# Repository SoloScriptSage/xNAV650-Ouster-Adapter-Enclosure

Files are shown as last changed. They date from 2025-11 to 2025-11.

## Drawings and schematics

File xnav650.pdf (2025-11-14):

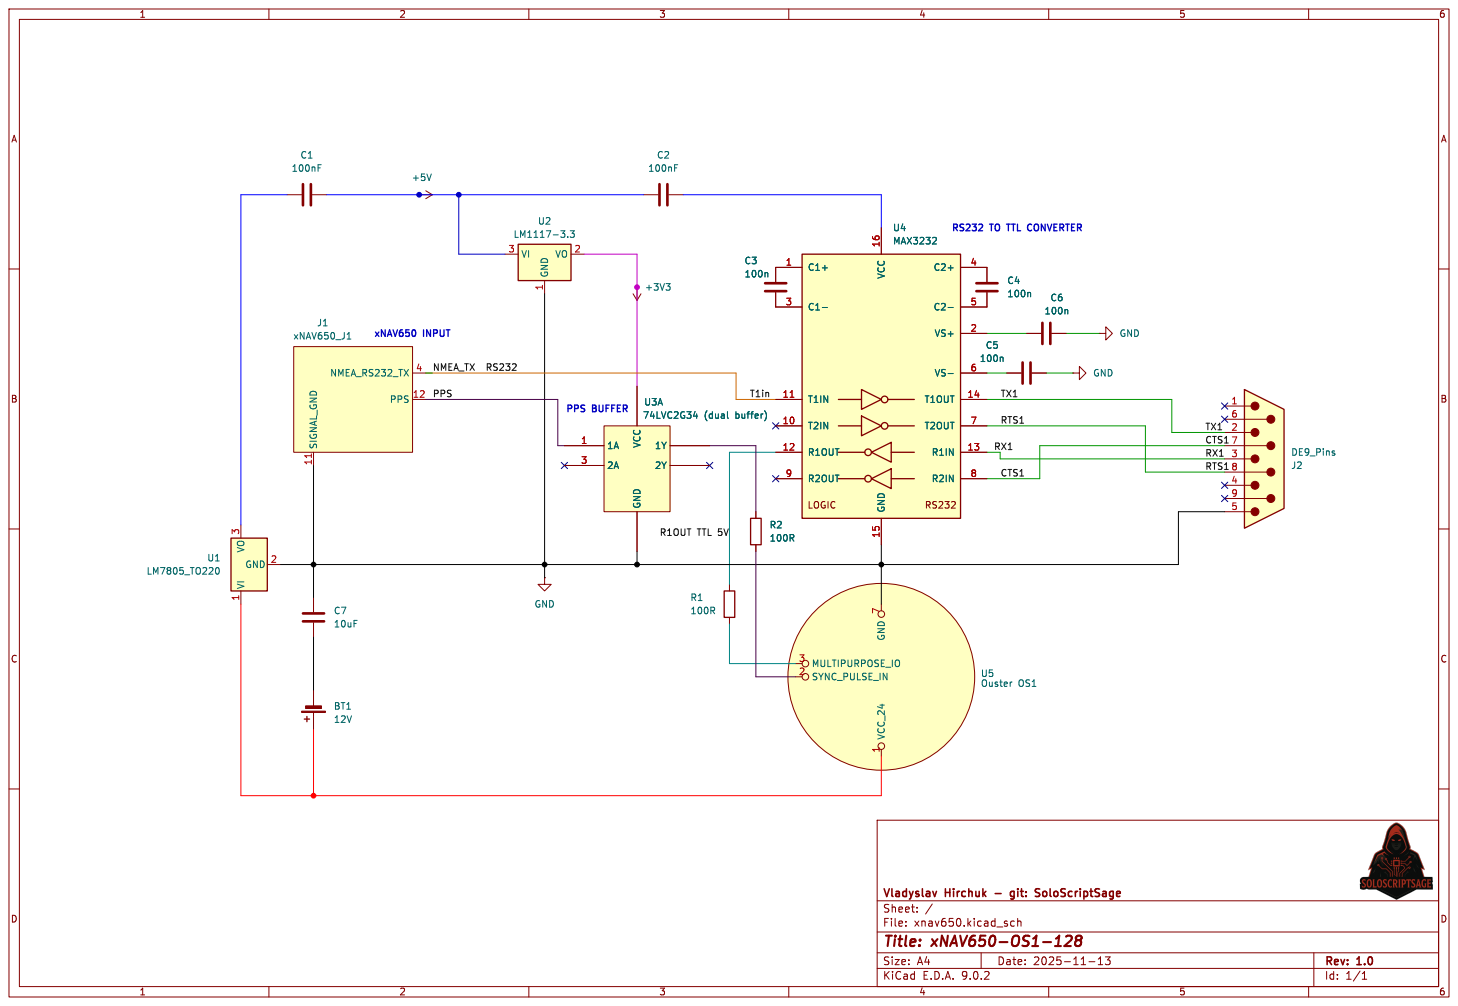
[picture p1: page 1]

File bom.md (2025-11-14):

# xNAV650 to Ouster OS1-128 Adapter
## Final Bill of Materials (BOM)

---

## INTEGRATED CIRCUITS

| Qty | Ref | Part Number | Description | Package | Manufacturer | Price (PLN) | Supplier | Part Link |
|-----|-----|---|---|---|---|---|---|---|
| 1 | U1 | MAX3232CPE+ | RS232 to TTL Transceiver, 3-5.5V | DIP-16 | Maxim/Analog Devices | ~8 zł | TME/Botland | [TME](https://www.tme.eu/pl/details/max3232cpe/konwertery-rs232/analog-devices/) |
| 1 | U2 | LM7805CT | 5V 1A Linear Voltage Regulator | TO-220 | STMicro/TI | ~2 zł | TME | [TME](https://www.tme.eu/pl/details/l7805cv/stabilizatory-napiecia-nieregulowane/stmicroelectronics/) |
| 1 | U3 | 74HC125N | Quad Buffer with 3-State Outputs | DIP-14 | Texas Instruments | ~2 zł | TME | [TME](https://www.tme.eu/pl/details/sn74hc125n/bramki-logiczne-cmos-smd/texas-instruments/) |

**Total ICs: ~12 zł**

---

## CAPACITORS

### Electrolytic Capacitors

| Qty | Ref | Value | Voltage | Type | Price (PLN) | Notes |
|-----|-----|---|---|---|---|---|
| 1 | C1 | 10µF | 25V | Electrolytic, Radial | ~0.30 zł | Input filter for LM7805 |
| 1 | C2 | 100µF | 16V | Electrolytic, Radial | ~0.50 zł | Output filter for LM7805 |

### Ceramic Capacitors

| Qty | Ref | Value | Voltage | Dielectric | Price (PLN) | Notes |
|-----|-----|---|---|---|---|---|
| 4 | C3, C4, C5, C6 | 1µF | 25V | X7R Ceramic | ~0.40 zł each | MAX3232 charge pump capacitors (MUST be X7R!) |
| 2 | C7, C8 | 100nF | 50V | X7R Ceramic | ~0.20 zł each | Decoupling capacitors for U1, U3 |

**Total Capacitors: ~3.50 zł**

---

## RESISTORS (1/4W, 5% Tolerance)

| Qty | Ref | Value | Power | Price (PLN) | Purpose |
|-----|-----|---|---|---|---|
| 2 | R1, R2 | 100Ω | 1/4W | ~0.10 zł each | Series resistors for signal protection |
| 1 | R3 | 1kΩ | 1/4W | ~0.10 zł | Current limiting resistor for LED |

**Total Resistors: ~0.30 zł**

---

## SEMICONDUCTORS

| Qty | Ref | Part | Description | Package | Price (PLN) | Notes |
|-----|-----|---|---|---|---|---|
| 1 | LED1 | Green LED | 5mm Green LED, 20mA | THT 5mm | ~0.30 zł | Power indicator |

**Total LEDs: ~0.30 zł**

---

## CONNECTORS

| Qty | Ref | Type | Part Number | Description | Price (PLN) | Supplier | Notes |
|-----|-----|---|---|---|---|---|---|
| 1 | J1 | Micro-D Female | Amphenol 17E15380000 or equiv. | 15-pin Micro-D Female Connector | ~15-20 zł | TME/Farnell | For xNAV650 cable connection |
| 1 | J3 | DC Barrel Jack | Standard 5.5×2.1mm | DC Power Jack, Panel Mount | ~1-2 zł | Botland/TME | 12V power input |
| 1 | - | Wire/Pigtail | - | 3-wire cable with ferrules/terminals | ~5 zł | Local electronics | For Ouster connection (Green/White/Black) |

**Total Connectors: ~21-27 zł**

---

## POWER SUPPLY

| Qty | Description | Specifications | Price (PLN) | Supplier | Notes |
|-----|---|---|---|---|---|
| 1 | Wall Adapter | 12V DC, 1A min, Center Positive, 5.5×2.1mm plug | ~15-25 zł | Botland/Allegro | Regulated switching adapter recommended |

**Total Power: ~20 zł**

---

## PCB & MECHANICAL

| Qty | Item | Description | Size/Type | Price (PLN) | Supplier | Notes |
|-----|---|---|---|---|---|---|
| 1 | PCB | Perfboard or Custom PCB | 60×40mm min | ~5-10 zł | Botland/TME | Single-sided perfboard OK |
| 1 | Heatsink | TO-220 Heatsink | Clip-on or adhesive | ~2-3 zł | TME | For LM7805 |
| 3 | IC Sockets | DIP Sockets | 16-pin (1×), 14-pin (1×) | ~1-2 zł each | TME | Optional but recommended |
| 1 | Enclosure | Plastic Box | 85×56×25mm or similar | ~8-15 zł | TME/Botland | Hammond 1591XXSSBK or similar |

**Total PCB/Mechanical: ~20-35 zł**

---

## ADDITIONAL MATERIALS

| Qty | Item | Description | Price (PLN) | Notes |
|-----|---|---|---|---|
| 1m | Wire | Multi-strand wire 22-24 AWG | ~2-3 zł | For internal connections |
| - | Solder | 60/40 or lead-free solder | ~5 zł | If not already available |
| - | Heat Shrink Tubing | Assorted sizes | ~5 zł | Cable strain relief |
| 4 | M3 Screws | For PCB mounting | ~1 zł | Optional |
| 4 | M3 Standoffs | 10mm height | ~2 zł | Optional |

**Total Additional: ~10-15 zł**

---

## COST SUMMARY

| Category | Cost (PLN) |
|---|---|
| Integrated Circuits | 12 |
| Capacitors | 3.50 |
| Resistors | 0.30 |
| LEDs | 0.30 |
| Connectors | 21-27 |
| Power Supply | 20 |
| PCB & Mechanical | 20-35 |
| Additional Materials | 10-15 |
| **TOTAL ESTIMATE** | **87-113 zł** |

**Average Total: ~100 zł (≈ $25 USD / €23)**

---

## RECOMMENDED SUPPLIERS (POLAND)

1. **TME (Transfer Multisort Elektronik)** - https://www.tme.eu/pl/
   - Best for: ICs, capacitors, resistors, connectors
   - Fast shipping within Poland
   - Professional components

2. **Botland** - https://botland.com.pl/
   - Best for: Power supplies, enclosures, basic components
   - Good for hobbyists
   - Warsaw-based

3. **Farnell/Newark** - https://pl.farnell.com/
   - Best for: Professional-grade connectors
   - International shipping

4. **Local Electronics Shops**
   - Cheaper for wire, heat shrink, basic tools

---

## ALTERNATIVE PARTS (If Primary Not Available)

| Component | Alternative Part Numbers |
|---|---|
| MAX3232CPE+ | MAX3232CPE, MAX3232CSE (SOIC-16 if SMD OK) |
| LM7805CT | L7805CV, MC7805CT, uA7805 |
| 74HC125N | 74HCT125N, SN74HC125N, CD74HC125 |
| Micro-D 15F | TE Connectivity 5745840-8, Norcomp 182-015-213R531 |

---

## ORDERING TIPS

1. **Order from TME first** - they have most components in stock
2. **Buy extras** - Get 2-3 of each capacitor type (they're cheap and easy to lose)
3. **IC Sockets** - Highly recommended for U1 and U3 (makes troubleshooting easier)
4. **Heatsink for LM7805** - Don't skip this! The regulator will get hot
5. **Check connector pins** - Verify Micro-D pinout matches your xNAV650 cable

---

## ASSEMBLY ORDER (RECOMMENDED)

1. Power supply section (U2, C1, C2)
2. Test: Apply 12V, verify 5V output
3. MAX3232 (U1) with charge pump caps (C3-C6)
4. 74HC125 (U3) buffer
5. Decoupling caps (C7, C8)
6. Resistors (R1, R2, R3) and LED
7. Connectors (J1, J3)
8. Wire connections to Ouster

---

## NOTES

- **CRITICAL**: C3-C6 MUST be X7R ceramic capacitors, not Y5V or Z5U (charge pump won't work with wrong type)
- **Polarity**: Watch electrolytic capacitor polarity (C1, C2) and LED polarity
- **74HC125 Enable**: Pin 1 (~1OE) must be tied to GND for the buffer to work
- **Heatsink**: LM7805 will dissipate ~7W of heat, heatsink is mandatory
- **Testing**: Test each section before connecting expensive equipment (xNAV650/Ouster)

---

## WHERE TO SAVE MONEY

If budget is tight, you can reduce costs by:
- Using perfboard instead of custom PCB (-5 zł)
- Skipping IC sockets (-3 zł)
- Using cheaper enclosure or 3D print (-10 zł)
- Re-using old power adapter if you have 12V regulated (-20 zł)

**Minimum viable cost: ~65-70 zł**

---

*Last Updated: 2025-11-14*
*Design: Corrected version based on schematic analysis*
